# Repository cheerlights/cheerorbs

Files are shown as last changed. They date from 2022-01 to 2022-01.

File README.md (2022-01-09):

# CheerOrb

Here is the Arduino code and the 3D printer STL files to make your own CheerOrb.

## Hardware

ESP8266  
[Wemos D1 mini](https://www.aliexpress.com/item/32651256441.html)  
Neopixel  
I use the single LED shield  
[WS2812B RGB shield](https://www.aliexpress.com/item/32757360867.html)  

If you choose to use the 7-LED shield from LOLIN [RGB LED Shield](https://www.wemos.cc/en/latest/d1_mini_shield/rgb_led.html) change line `70` of the sketch from  
`Adafruit_NeoPixel pixel = Adafruit_NeoPixel(1, D2, ORDER); // 1 pixels on pin D2`  
to  
`Adafruit_NeoPixel pixel = Adafruit_NeoPixel(7, D4, ORDER); // 7 pixels on pin D4`

Solder the top and  bottom through-pin headers onto the Wemos board and attach the neopixel shield on top, making sure you get it the right way round (so all the pin labels align correctly).

Power with a Micro-USB cable.

## Software

Download the .ino file and build it in the Arduino IDE.  
You need a few extra libraries, installed through the library manager.

## 3D printed case
Print the base and top in translucent filament on “normal” setting (takes about 2 hours for the top and 30 mins for the base).

### Assembly
- Put a drop of superglue onto each of the 4 pin holders.  
- Push the wemos board down into the holders.   
- Wait for the glue to dry.  
- Put a drop of superglue in the middle of the 3 edges of the base that are not the USB socket edge.   
- Push the top firmly but carefully down onto the base, making sure the cut-out is next to the USB socket.  
- Wait for the glue to dry.  

## Configuring your CheerOrb
Connect your CheerOrb to your WiFi using the instructions here: [CheerOrb instructions](https://cheerlights.com/orb).

**Have fun :)**

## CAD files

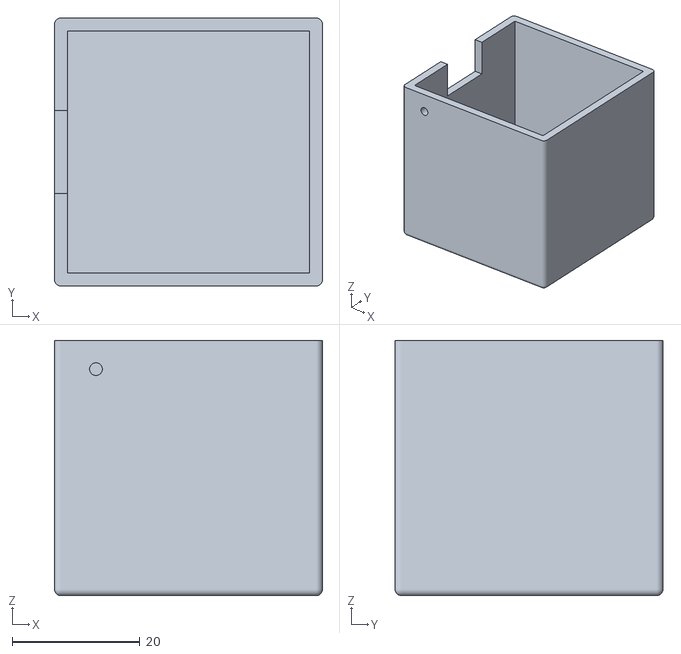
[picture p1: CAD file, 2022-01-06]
squorb v4 - top.stl
42.0 x 42.0 x 40.0

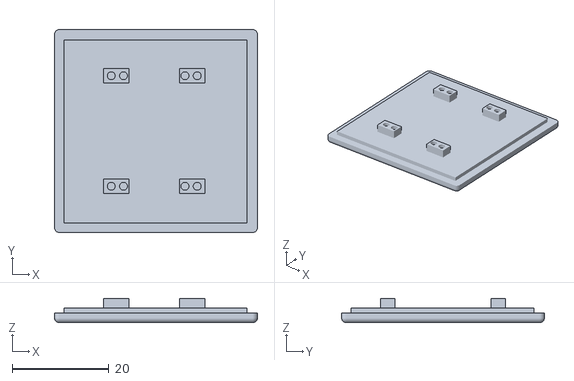
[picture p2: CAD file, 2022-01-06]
squorb v4 - base.stl
42.0 x 42.0 x 5.00

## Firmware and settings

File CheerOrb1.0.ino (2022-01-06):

  /* 
 *  CheerOrb
 *  
 *  Cheerlights on a Neopixel on a Wemos ESP8266 using MQTT

Neopixel application using a WeMoS D1 ESP-8266 board connecting to an MQTT broker
expects messages of the form: "#rrggbb" and sets the LED to that colour


By Andy Stanford-Clark (@andysc)
 May 2016 to
 Dec 2021


*** update the VERSION string!!! ***

1.0 CheerOrb v1.0  strip out all the provisioning stuff. Still use Wifi manager
 
 

 use board "WeMos D1 R2 & mini"


*/


#define VERSION "1.0"

// define this if you want to force a reset of the wifi credentials at the start
//#define RESET_WIFI


// Access Point name over-ride
// if this is defined, use that instead of the stored "ident" string
#define AP_NAME "CheerOrb"


#include <Adafruit_NeoPixel.h>

// it seems GRB is the default
#define ORDER NEO_GRB
// change it to RGB if it's one that flashes white at power up
//#define ORDER NEO_RGB


#include <ESP8266WiFi.h>

#include <WiFiManager.h>          //https://github.com/tzapu/WiFiManager WiFi Configuration Magic

#include <PubSubClient.h>

#include <Ticker.h>

// remember to change MQTT_KEEPALIVE to 60 in the header file {arduino installation}/libraries/PubSubClient/src/PubsSubClient.h

/////////////////////////////////////////////////////////////////////////////////////////////



// subscribe to this for commands:
#define COMMAND_TOPIC "cheerlightsRGB"


WiFiClient espClient;
WiFiManager wifiManager;

PubSubClient client(espClient);

//Change this if using different number of neopixels or different pin
Adafruit_NeoPixel pixel = Adafruit_NeoPixel(1, D2, ORDER); // one pixel, on pin D2

Ticker ticker;


// flashes this colour when connecting to wifi:
static uint32_t wifi_colour = pixel.Color(128, 0, 128); // magenta

// flashes this colour when in AP config mode
static uint32_t config_colour = pixel.Color(0, 0, 128); // blue

// flashes this colour when connecting to MQTT:
static uint32_t mqtt_colour = pixel.Color(0, 128, 128); // cyan

static uint32_t current_colour = 0x000000; // black
static uint32_t current_LED = current_colour;



// broker connection information
char broker[] = "mqtt.cheerlights.com";
int port = 1883;
char clientID[128];

char mac_string[20]; // mac address

/////////////////////////////////////////////////////////////////////////////////////////////


void setup() {
  
  Serial.begin(9600);
 
  pixel.begin();
  delay(10);
  pixel.show(); // Initialize all pixels to 'off'

  delay(500);

  Serial.println();
  Serial.println("CheerOrb by @andysc");
  Serial.print("Firmware version ");
  Serial.println(VERSION);

  Serial.print("Acess Point name set to: ");
  Serial.println(AP_NAME);
  
  // make it wait longer when trying to connect
  wifiManager.setConnectTimeout(30);




#ifdef RESET_WIFI

  Serial.print("Looking for ");
  Serial.print(WiFi.SSID().c_str());
  Serial.print(" / ");
  Serial.println(WiFi.psk().c_str());

  Serial.println("*** Resetting WiFi credentials ***");
  WiFi.mode(WIFI_STA);
  
  WiFi.persistent(true);
  WiFi.disconnect(true);
  WiFi.persistent(false);

  // reset so we don't get confused and reconfigure it and then get it wiped again
  delay(2000);
  ESP.reset();
#endif


    
      // display mac address
      mac_address();
      

      Serial.print("Looking for ");
      Serial.print(WiFi.SSID().c_str());
      Serial.print(" / ");
      Serial.println(WiFi.psk().c_str());
    
      // connecting to wifi colour
      set_colour(wifi_colour); 
      ticker.attach(1, tick);

      // call us back when it's connected so we can reset the pixel
      wifiManager.setAPCallback(configModeCallback);
      
      // set the AP name it comes up as
      if (!wifiManager.autoConnect(AP_NAME)) {

        Serial.println("failed to connect to an access point");
        delay(2000);
        // not much else to do, really, other than try again
        ESP.reset();
      }
    
      Serial.println("connected to wifi!");
      ticker.detach();
    
      // reset the pixel to show we've connected successfully, before going for MQTT connection colour
      set_colour(0);

      Serial.print("connecting to broker: ");
      Serial.print(broker);
      Serial.print(":");
      Serial.println(port);

      client.setServer(broker, port);
      client.setCallback(callback);


    // create unique client ID
    // last 2 octets of MAC address plus some time bits
    sprintf(clientID, "%s_%s_%05d","CheerOrb", (char *)(mac_string+9), millis()%100000);
 
    Serial.print("clientID: ");
    Serial.println(clientID);

}


void configModeCallback (WiFiManager *myWiFiManager) {
  Serial.println("Entered config mode");
  Serial.println(WiFi.softAPIP());

  Serial.println(myWiFiManager->getConfigPortalSSID());

  ticker.detach();
  set_colour(config_colour);
  ticker.attach(1, tick);
}


void tick()
{
  toggle_pixel();
}



void callback(char* topic, byte* payload, unsigned int length) {
  char content[10];
  
  // #rrggbb
  
  Serial.print("Message arrived: ");


  if (length != 7)
  {
    Serial.print("expected 7 bytfes, got ");
    Serial.println(length);
    return;
  }

  // "else"...
  // "+1" to skip over the '#'
  strncpy(content, (char *) (payload+1), length-1);
  content[length-1] = '\0';


  Serial.print("'");
  Serial.print((char)payload[0]);
  Serial.print(content);
  Serial.println("'");

  // convert the hex number to decimal
  uint32_t value = strtol(content, 0, 16);

  set_colour(value);
  
}


void wait_for_wifi()
{
  
  Serial.println("waiting for Wifi");
  
  // connecting to wifi colour
  set_colour(wifi_colour);
  
  while (WiFi.status() != WL_CONNECTED) {
    delay(1000);
    toggle_pixel();
    Serial.print(".");
  }
  Serial.println();
  Serial.println("WiFi connected");
   
}


void reconnect() {
  
  boolean first = true;

  // Loop until we're reconnected to the broker
  while (!client.connected()) {

    if (WiFi.status() != WL_CONNECTED) {
      ticker.detach();
      wait_for_wifi();
      first = true;
    }

    Serial.print("Attempting MQTT connection...");
    if (first) {
      // now we're on wifi, show connecting to MQTT colour
      set_colour(mqtt_colour);
      first = false;

      // flash every 2 sec while we're connecting to broker
      ticker.attach(2,tick);
    }

    if (client.connect(clientID)) {
      Serial.println("connected");
    } 
    else {
      Serial.print("failed, rc=");
      Serial.println(client.state());
      
      // wait 5 seconds to prevent connect storms
      delay(5000);
    }
    
  }

  ticker.detach();

  delay(1000); // wait a second to make sure they saw the mqtt_colour
  set_colour(0); // clear pixel when connected (black)
  
  // subscribe to the command topic
  Serial.print("subscribing to '");
  Serial.print(COMMAND_TOPIC);
  Serial.println("'");
  
  client.subscribe(COMMAND_TOPIC);

}


void set_colour(uint32_t colour) {
  
  set_pixels(colour);
  // Updates current_LED with what the user last requested,
  // so we can toggle it to black and back again.
  
  current_colour = colour;
}



void set_pixels(uint32_t colour) {
  
  for (int i = 0; i < pixel.numPixels(); i++) {
    pixel.setPixelColor(i, colour);
  }
  pixel.show();

  // Store current actual LED colour
  // (which may be black if toggling code turned it off.)
  current_LED = colour;
}


void toggle_pixel() {

  if (current_LED == 0) 
  {
    // if it's black, set it to the stored colour
    set_pixels(current_colour);
  } 
  else
  {
    // otherwise set it to black
    set_pixels(0);
  }
}


void loop() {
       
    if (!client.connected()) {
      reconnect();
    }
    
    // service the MQTT  client
    client.loop();
}



void mac_address() {
  byte mac[6];                   

  WiFi.macAddress(mac);   // the MAC address of your Wifi shield

  sprintf(mac_string, "%02x:%02x:%02x:%02x:%02x:%02x",
        mac[0],mac[1],mac[2],mac[3],mac[4],mac[5]);

  Serial.println(mac_string);
}

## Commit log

2022-01-06 STL files to 3D print a CheerOrb
    [squorb v4 - base.stl, squorb v4 - top.stl]
2022-01-06 Assembly instructions
2022-01-06 updated for 7-LED shield
